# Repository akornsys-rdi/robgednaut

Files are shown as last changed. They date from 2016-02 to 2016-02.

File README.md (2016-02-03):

# robgednaut #


GNU/GPL (https://www.gnu.org/licenses/gpl.html "GNU General Public License")

### Robust and easy-to-use introduction-to-robotics platform ###

         ___     _              
        | _ \___| |__  ___ _ _  
        |   / _ \ '_ \/ -_) ' \ 
        |_|_\___/_.__/\___|_||_|

_Robgednaut_ (from **Rob**otic, Rug**ged**, and _-**naut**_ [like 
_astronaut_]), commonly _Roben_, it's a simple hardware platform for the 
introduction to robotics. Use an Arduino Nano to provide four multifunction 
connections. Also has ability to move up to two motors with the replaceable 
driver included. It can be used stand-alone or controlled from a computer, also 
it has numerous protections so you don't have to worry about if you break it!

Robgednaut is free software/hardware. See License Information below.

## Repository Contents ##

-   `/img/`: Graphic resources used --if not told otherwise-- as part of the 
documentation.  
-   `/3d/` 3D design source code.
    *   `/3d/bin/` Files resulting from the compilation of 3D designs (`STL` 
files).  
-   `/brd/` Hardware source code.  
    *    `/brd/bin/` Files resulting from the compilation of hardware (`PDF` 
and Gerber files).  
-   `/src/` Firmware source code.  
    *   `/src/bin/` Files resulting from the compilation of code (`HEX` files).

Robgednaut can be obtained on GitHub:
[Robgednaut](https://github.com/akornsys-rdi/robgednaut "Robgednaut").

## Installation and use ##

_Roben_ is very easy to use! You just need a Arduino Nano with the firmware we 
provide (compatible with firmata) or your own, your _Robgednaut_, and a power 
supply (3 to 32v max). Connect things to their I/O and enjoy making it work!  
It can be managed from Scratch by Firmata gateway, or from your own software.  
> **Warning**: Make sure you have the proper firmware BEFORE you connect your 
> Arduino Nano to _Robgednaut_. Not doing so may damage your Arduino.

#### Pinout ####

|Robgednaut|Arduino|Function|
|---|---|---|
| +V | - | 5v power out |
| GND | GND | Ground |
| A | D2, A7 | Analog input, digital I/O, `INT` |
| B | D3, A6 | Analog input, digital I/O, `INT`, `PWM` |
| C | D13, A4 | Analog input, digital I/O, `SDA`, `SCK` |
| D | D11, A5 | Analog input, digital I/O, `PWM`, `SCL`, `MOSI` |
| 1+ | D8 (en), D10 (`PWM`) | Half H-Bridge 1 output |
| 1- | D7 (en), D5 (`PWM`) | Half H-Bridge 1 output |
| 2+ | D8 (en), D9 (`PWM`) | Half H-Bridge 2 output |
| 2- | D7 (en), D6 (`PWM`) | Half H-Bridge 2 output |
| Internal | D4 | Piezo buzzer |
| Internal | D12 | Red LED |
| Internal | A0 | Yellow LED |
| Internal | A1 | Green LED |
| Internal | A2 | Push button |
| Internal | A3 | Push button |

## License Information ##

Firmware released under
[GNU/GPL](https://www.gnu.org/licenses/gpl.html "GNU General Public License").
See `/src/` folder.

The hardware design is released under
[GNU/GPL](https://www.gnu.org/licenses/gpl.html "GNU General Public License").
See `/brd/` folder.  
Source code hardware is considered any file created and stored by the CAD tool 
with design information. To KiCAD are mainly `SCH`, `NET`, `KICAD_PCB` files 
and associated.  
Binary hardware is considered any file created from source code. To KiCAD they 
are mainly `PDF`, `CSV` files and manufacturing files (e.g. gerber).  
Binary hardware execution is considered any process derived from binary 
hardware, such as manufacturing.

The 3D designs are released under
[GNU/GPL](https://www.gnu.org/licenses/gpl.html "GNU General Public License").
See `/3d/` folder.  
Source code 3D is considered any file created and stored by the CAD tool with 
design information. To OpenSCAD are mainly `SCAD` files.  
Binary 3D is considered any file created from source code. To OpenSCAD they are 
mainly rendering and manufacturing files (e.g. `STL`).  
Binary 3D execution is considered any process derived from binary 3D, such as 
manufacturing.

See the corresponding `COPYING` file.

## Version History ##

Robgednaut uses
[Semantic Versioning](http://semver.org/ "Semantic Versioning").

Robgednaut version 
[v2.0.0](https://github.com/akornsys-rdi/robgednaut/archive/v2.0.0.zip "v2.0.0")
is the latest stable version.

If you are interested, you can view the version history:
[`ChangeLog`](ChangeLog.md)

## Contribute ##

Feel free to submit bugs or patches, feature requests, etc. using
[GitHub issues](https://github.com/akornsys-rdi/robgednaut/issues "GitHub issues")
and
[Pull Requests](https://github.com/akornsys-rdi/robgednaut/pulls "Pull Requests")

You can read the information about the developers:
[`AUTHORS`](AUTHORS.md)

_Last modification: 2016-02-03_  
_This file was automatically generated by KodeUtils 1.0.2_

* * *

Copyright (C) 2015-2016 kwendenarmo. This file is part of Robgednaut

Robgednaut is free software; you can redistribute it and/or modify it under the 
terms of the GNU General Public License as published by the Free Software 
Foundation; either version 3 of the License, or (at your option) any later 
version.

Robgednaut is distributed in the hope that it will be useful, but WITHOUT ANY 
WARRANTY; without even the implied warranty of MERCHANTABILITY or FITNESS FOR A 
PARTICULAR PURPOSE.  See the GNU General Public License for more details

You should have received a copy of the GNU General Public License along with 
this program.  If not, see 
<[http://www.gnu.org/licenses/](http://www.gnu.org/licenses/ "http://www.gnu.org/licenses/")>.

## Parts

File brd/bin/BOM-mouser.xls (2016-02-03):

Robgednaut 2
Mouser REF | Fabr. N.º | Fabricante | Desc. | RoHS | Ciclo de vida | N.º Ref. del cliente | Ctd. pedido | Precio (EUR) | Ext.: (EUR)
855-M20-8771646 | M20-8771646 | Harwin | Alojamientos de cables y cabecera 16 SIL VERTICAL SMT HEADER TIN | Cumple RoHS |  |  | 1 | 0,733 € | 0,73 €
710-61303211821 | 61303211821 | Wurth Electronics | Alojamientos de cables y cabecera WR-PHD 2.54mm 32Pin Socket Header | Cumple RoHS |  |  | 1 | 1,48 € | 1,48 €
502-RAPC722X | RAPC722X | Switchcraft | Conectores de potencia de CC RT ANGL PWK JK PIN D | Cumple RoHS |  |  | 1 | 0,979 € | 0,98 €
667-ERJ-6ENF1802V | ERJ-6ENF1802V | Panasonic | Resistores de pel&iacute;cula gruesa - SMD 0805 18Kohms 1% Tol | Conforme con RoHS por exención |  |  | 1 | 0,091 € | 0,09 €
720-LYR976-PS-36 | LY R976-PS-36 | Osram Opto Semiconductor | LED estándar - SMD Yellow, 588nm 280mcd, 20mA | Cumple RoHS |  |  | 1 | 0,091 € | 0,09 €
720-LGR971-KN-1 | LG R971-KN-1 | Osram Opto Semiconductor | LED estándar - SMD Green, 570nm 26mcd, 20mA | Cumple RoHS |  |  | 1 | 0,091 € | 0,09 €
720-LSQ976-NR-1 | LS Q976-NR-1 | Osram Opto Semiconductor | LED estándar - SMD Super Red, 633nm 180mcd, 20mA | Cumple RoHS |  |  | 1 | 0,091 € | 0,09 €
511-LM2902DT | LM2902DT | STMicroelectronics | Amplificadores operacionales - Op Amps Quad Low Power | Cumple RoHS |  |  | 1 | 0,30 € | 0,30 €
506-FSM18JH | FSM18JH | TE Connectivity | Interruptores táctiles 6MM ACTHIGH TEMP TACT SWITCH | Cumple RoHS |  |  | 2 | 0,093 € | 0,19 €
665-AT1224TWT5V2R | AT-1224-TWT-5V-2-R | PUI Audio | Altavoces y transductores EM 5Vpk 2400Hz 87dBA Top Fire | Cumple RoHS |  |  | 1 | 0,503 € | 0,50 €
821-BZT52B5V1 | BZT52B5V1 | Taiwan Semiconductor | Diodos Zener 5.1 Volt 410mW 2% | Conforme con RoHS por exención |  |  | 4 | 0,162 € | 0,65 €
571-1-2199300-2 | 1-2199300-2 | TE Connectivity | Zócalos de CI y de componentes 32P DIP SKT 600 CL OTC | No aplicable |  |  | 1 | 0,701 € | 0,70 €
571-1-2199298-4 | 1-2199298-4 | TE Connectivity | Zócalos de CI y de componentes 16P DIP SKT 300 CL LADDER | Cumple RoHS |  |  | 1 | 0,115 € | 0,12 €
992-ARD-NANO30 | A000005 | Gravitech | Equipos y placas de desarrollo - AVR ARDUINO NANO V3 A000005 | Cumple RoHS |  |  | 1 | 30,79 € | 30,79 €
595-SN754410NE | SN754410NE | Texas Instruments | Controladores y unidades para motores / movimiento / ignición Quad Half-Hs | Cumple RoHS |  |  | 1 | 2,19 € | 2,19 €
611-JS202011SCQN | JS202011SCQN | C&K Components | Conmutadores deslizantes DPDT SMT .3A | Cumple RoHS |  |  | 1 | 0,40 € | 0,40 €
583-TCMBD914 | TCMBD914 | Rectron | Rectificadores 1N914 | Cumple RoHS |  |  | 1 | 0,043 € | 0,04 €
583-BC856A-T | BC856A-T | Rectron | Transistores bipolares - BJT Transistor PNP | Cumple RoHS |  |  | 1 | 0,065 € | 0,07 €
720-LOR976-PS-1 | LO R976-PS-1 | Osram Opto Semiconductor | LED estándar - SMD Orange, 606nm 280mcd, 20mA | Cumple RoHS |  |  | 9 | 0,091 € | 0,82 €
667-ERJ-6GEYJ221V | ERJ-6GEYJ221V | Panasonic | Resistores de pel&iacute;cula gruesa - SMD 0805 220ohms 5% Tol | Conforme con RoHS por exención |  |  | 17 | 0,016 € | 0,27 €
720-LBQ39GL2N2351 | LB Q39G-L2N2-35-1 | Osram Opto Semiconductor | LED estándar - SMD Blue, 470nm 45mcd, 5mA | Cumple RoHS |  |  | 1 | 0,146 € | 0,15 €
571-1776493-2 | 1776493-2 | TE Connectivity | Bloques terminales fijos SIDE WIRE ENTRY TB 5.08MM BL | Cumple RoHS |  |  | 1 | 0,317 € | 0,32 €
530-0ZCF0150FF2C | 0ZCF0150FF2C | Bel | Fusibles de restablecimiento (PPTC) Fuse | Cumple RoHS |  |  | 1 | 0,21 € | 0,21 €
621-B340-F | B340-13-F | Diodes Incorporated | Diodos y rectificadores Schottky 40V 3A | Conforme con RoHS por exención |  |  | 2 | 0,366 € | 0,73 €
771-BUK7Y98-80EX | BUK7Y98-80EX | NXP | MOSFET N-channel 80 V 98 mOhm MOSFET | Cumple RoHS |  |  | 1 | 0,471 € | 0,47 €
581-SD2114S040S8R0 | SD2114S040S8R0 | AVX | Diodos y rectificadores Schottky 40volts 8A SIZE 2114 | Cumple RoHS |  |  | 1 | 0,54 € | 0,54 €
652-SRR1210-220M | SRR1210-220M | Bourns | Inductores fijos 22uH 20% SMD 1210 | Cumple RoHS |  |  | 1 | 1,00 € | 1,00 €
652-SDR1307-680KL | SDR1307-680KL | Bourns | Inductores fijos 68uH 10% SMD 1307 | Cumple RoHS |  |  | 1 | 0,786 € | 0,79 €
667-ERJ-6ENF1543V | ERJ-6ENF1543V | Panasonic | Resistores de pel&iacute;cula gruesa - SMD 0805 154Kohms 1% Tol | Conforme con RoHS por exención |  |  | 1 | 0,091 € | 0,09 €
667-ERJ-6ENF2942V | ERJ-6ENF2942V | Panasonic | Resistores de pel&iacute;cula gruesa - SMD 0805 29.4Kohms 1% Tol | Conforme con RoHS por exención |  |  | 1 | 0,091 € | 0,09 €
667-ERJ-6ENF1002V | ERJ-6ENF1002V | Panasonic | Resistores de pel&iacute;cula gruesa - SMD 0805 10Kohms 1% Tol | Conforme con RoHS por exención |  |  | 7 | 0,10 € | 0,70 €
667-ERJ-6ENF1961V | ERJ-6ENF1961V | Panasonic | Resistores de pel&iacute;cula gruesa - SMD 0805 1.96Kohms 1% Tol | Conforme con RoHS por exención |  |  | 1 | 0,091 € | 0,09 €
667-ERJ-6ENF1000V | ERJ-6ENF1000V | Panasonic | Resistores de pel&iacute;cula gruesa - SMD 0805 100ohms 1% Tol | Conforme con RoHS por exención |  |  | 1 | 0,10 € | 0,10 €
667-ERJ-6ENF20R0V | ERJ-6ENF20R0V | Panasonic | Resistores de pel&iacute;cula gruesa - SMD 0805 20.0ohms 1% Tol | Conforme con RoHS por exención |  |  | 1 | 0,091 € | 0,09 €
754-KRL1632EMR018FT5 | KRL1632E-M-R018-F-T5 | Susumu | Resistores de detecci&oacute;n de corriente - SMD 3/4w 18m ohm 1% | Cumple RoHS |  |  | 1 | 0,494 € | 0,49 €
647-UWT1A471MNL1GS | UWT1A471MNL1GS | Nichicon | Capacitadores electrolíticos de aluminio - SMD 10volts 470uF 105c 8x10 | Cumple RoHS |  |  | 2 | 0,485 € | 0,97 €
140-VE100M1HTR0505 | VE-100M1HTR-0505 | Lelon | Capacitadores electrolíticos de aluminio - SMD 50 Volts 10uF 20% 5x5.3 | Cumple RoHS |  |  | 1 | 0,205 € | 0,21 €
963-UMK316AB7475KL-T | UMK316AB7475KL-T | Taiyo Yuden | Condensadores de cerámica multicapa (MLCC- SMD/SMT) 4.7uF 50Volts X7R +/-10% 1206 STD | Cumple RoHS |  |  | 1 | 0,256 € | 0,26 €
77-VJ0805Y394KXJTBC | VJ0805Y394KXJTW1BC | Vishay | Condensadores de cerámica multicapa (MLCC- SMD/SMT) 0805 0.39uF 16volts X7R 10% | Cumple RoHS |  |  | 1 | 0,091 € | 0,09 €
80-C0805C104K5R | C0805C104K5RACTU | Kemet | Condensadores de cerámica multicapa (MLCC- SMD/SMT) 50volts 0.1uF X7R 10% | Cumple RoHS |  |  | 3 | 0,091 € | 0,27 €
81-GRM2165C1H242JA01 | GRM2165C1H242JA01D | Murata | Condensadores de cerámica multicapa (MLCC- SMD/SMT) 0805 2400pF 50volts C0G 5% | Cumple RoHS |  |  | 1 | 0,199 € | 0,20 €
81-GRM2165C1H162JA1D | GRM2165C1H162JA01D | Murata | Condensadores de cerámica multicapa (MLCC- SMD/SMT) 0805 1600pF 50volt C0G +/-5% | Cumple RoHS |  |  | 1 | 0,181 € | 0,18 €
926-LM3488MM/NOPB | LM3488MM/NOPB | Texas Instruments | Controladores de conmutación HI EFF LOW-SIDE N CH CONTROLLER | Cumple RoHS |  |  | 1 | 1,92 € | 1,92 €

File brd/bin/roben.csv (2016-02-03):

Source: | /home/kwendenarmo/git-repos/local/akornsys-rdi/robgednaut/brd/roben.sch
Date: | mié 03 feb 2016 19:03:34 CET
Tool: | Eeschema 4.0.1-3.201512221402+6198~38~ubuntu14.04.1-stable
Generator: | /usr/share/doc/kicad/scripts/bom-in-python/bom_csv_grouped_by_value_with_fp.py
Component Count: | 90
Ref | Qnty | Value | Cmp name | Footprint | Description | Vendor
C1, | 1 | 10uF | CP | Capacitors_SMD:c_elec_5x5.3 | Polarised capacitor | VE-100M1HTR-0505
C3, | 1 | 1.6nF | C | Capacitors_SMD:C_0805_HandSoldering | Unpolarized capacitor | GRM2165C1H162JA01D
C4, | 1 | 390nF | C | Capacitors_SMD:C_0805_HandSoldering | Unpolarized capacitor | VJ0805Y394KXJTW1BC
C5, | 1 | 2.4nF | C | Capacitors_SMD:C_0805_HandSoldering | Unpolarized capacitor | GRM2165C1H242JA01D
C6, | 1 | 4.7uF | C | Capacitors_SMD:C_1206_HandSoldering | Unpolarized capacitor | UMK316AB7475KL-T
C7, C8, | 2 | 470uF | CP | Capacitors_SMD:c_elec_8x10 | Polarised capacitor | UWT1A471MNL1GS
C9, C2, C10, | 3 | 100nF | C | Capacitors_SMD:C_0805_HandSoldering | Unpolarized capacitor | C0805C104K5RACTU
D1, | 1 | RED | LED | LEDs:LED-0805 |  | LS Q976-NR-1
D3, | 1 | YELLOW | LED | LEDs:LED-0805 |  | LY R976-PS-36
D4, | 1 | GREEN | LED | LEDs:LED-0805 |  | LG R971-KN-1
D5, | 1 | SD2114S040S8R0 | D | Diodes_SMD:Diode-SMB_Handsoldering | Diode | SD2114S040S8R0
D6, | 1 | BLUE | LED | LEDs:LED-0805 |  | LB Q39G-L2N2-35-1
D11, | 1 | TCMBD914 | Diode-sot23 | Housings_SOT-23_SOT-143_TSOT-6:SOT-23_Handsoldering | Diode | TCMBD914
D13, D2, | 2 | B340 | D_Schottky | Diodes_SMD:Diode-SMC_Handsoldering | Diode schottky | B340-F
D14, D18, D15, D19, | 4 | 5V1 | ZENER | Diodes_SMD:SOD-123 | Diode zener | BZT52B5V1
D16, D12, D20, D17, D21, D7, D8, D9, D10, | 9 | ORANGE | LED | LEDs:LED-0805 |  | LO R976-PS-1
F1, | 1 | 1.5A PPTC | F_Small | Fuse_Holders_and_Fuses:Fuse_SMD2920 | Fuse | 0ZCF0150FF2C
J1, | 1 | POWER IN | CONN_01X03 | asrdi-conn:combo-barrel5.5x2.1-2p5.08 | Connector 01x03 | 1776493-2 / RAPC722X
J2, | 1 | BT HC-05 | CONN_01X06 | asrdi-socket:HC-05 | Connector 01x06 | 61303211821
J3, | 1 | 1+ | CONN_01X01 | Wire_Pads:SolderWirePad_single_2-5mmDrill | Connector 01x01
J4, | 1 | 1- | CONN_01X01 | Wire_Pads:SolderWirePad_single_2-5mmDrill | Connector 01x01
J5, | 1 | 2+ | CONN_01X01 | Wire_Pads:SolderWirePad_single_2-5mmDrill | Connector 01x01
J6, | 1 | 2- | CONN_01X01 | Wire_Pads:SolderWirePad_single_2-5mmDrill | Connector 01x01
J7, J9, | 2 | +V | CONN_01X01 | Wire_Pads:SolderWirePad_single_2-5mmDrill | Connector 01x01
J10, J8, | 2 | GND | CONN_01X01 | Wire_Pads:SolderWirePad_single_2-5mmDrill | Connector 01x01
J11, | 1 | A | CONN_01X01 | Wire_Pads:SolderWirePad_single_2-5mmDrill | Connector 01x01
J12, | 1 | C | CONN_01X01 | Wire_Pads:SolderWirePad_single_2-5mmDrill | Connector 01x01
J13, | 1 | B | CONN_01X01 | Wire_Pads:SolderWirePad_single_2-5mmDrill | Connector 01x01
J14, | 1 | D | CONN_01X01 | Wire_Pads:SolderWirePad_single_2-5mmDrill | Connector 01x01
JP1, | 1 | VSEL | JUMPER3 | asrdi-conn:M20-87703xx |  | M20-8771646
L1, | 1 | 22uH | INDUCTOR | asrdi-discrete:coil-12x12h10 |  | SRR1210-220M
L2, | 1 | 68uH | INDUCTOR | asrdi-discrete:coil-13x13H7 |  | SDR1307-680KL
LS1, | 1 | AT-1224-TWT-5V-2-R | Crystal | asrdi-buzzer:AT-1224-TWT-5V-2-R | Two pin crystal | AT-1224-TWT-5V-2-R
Q1, | 1 | BUK7Y98 | IRF8721PBF-1 | Power_Packages_SMD:SOT-669_LFPAK_ThermalVias-1 | 30V Vds, 14A Id, HEXFET MOSFET, SO-8 | BUK7Y98-80EX
Q2, | 1 | BC856 | Q_PNP_CBE | Housings_SOT-23_SOT-143_TSOT-6:SOT-23_Handsoldering | Transistor PNP (general) | BC856A-T
R2, | 1 | 18k | R | Resistors_SMD:R_0805_HandSoldering | Resistor | ERJ-6ENF1802V
R6, | 1 | 20R | R | Resistors_SMD:R_0805_HandSoldering | Resistor | ERJ-6ENF20R0V
R8, | 1 | 154k | R | Resistors_SMD:R_0805_HandSoldering | Resistor | ERJ-6ENF1543V
R9, | 1 | 1k96 | R | Resistors_SMD:R_0805_HandSoldering | Resistor | ERJ-6ENF1961V
R14, | 1 | 100R | R | Resistors_SMD:R_0805_HandSoldering | Resistor | ERJ-6ENF1000V
R15, | 1 | 18m | R | asrdi-discrete:0612 | Resistor | KRL1632E-M-R018-F-T5
R16, | 1 | 29k4 | R | Resistors_SMD:R_0805_HandSoldering | Resistor | ERJ-6ENF2942V
R17, R1, R12, R7, R5, R13, R3, | 7 | 10k | R | Resistors_SMD:R_0805_HandSoldering | Resistor | ERJ-6ENF1002V
R24, R22, R26, R10, R11, R4, R23, R28, R30, R25, R27, R29, R31, R18, R19, R20, R21, | 17 | 220R | R | Resistors_SMD:R_0805_HandSoldering | Resistor | ERJ-6GEYJ221V
SW1, | 1 | POWER ON | Switch_SPDT_x2 | asrdi-switch:JS202011SCQN | Double Single Pole Double Throw (SPDT) switch | JS202011SCQN
SW2, SW3, | 2 | SW_PUSH | SW_PUSH | asrdi-switch:FSMxxJxH | Button | FSM18JH
U1, | 1 | Ardunano | Ardunano | asrdi-socket:Ardunano |  | A000005 / 1-2199300-2
U2, | 1 | LM3488 | LM3488 | Housings_SSOP:TSSOP-8_3x3mm_Pitch0.65mm |  | LM3488MM/NOPB
U3, | 1 | SN754410N | SN754410N | Housings_DIP:DIP-16__300_ELL |  | SN754410NE / 1-2199298-4
U4, | 1 | LM2902N | LM2902N | Housings_SOIC:SOIC-14_3.9x8.7mm_Pitch1.27mm | Quad Op amp. | LM2902DT

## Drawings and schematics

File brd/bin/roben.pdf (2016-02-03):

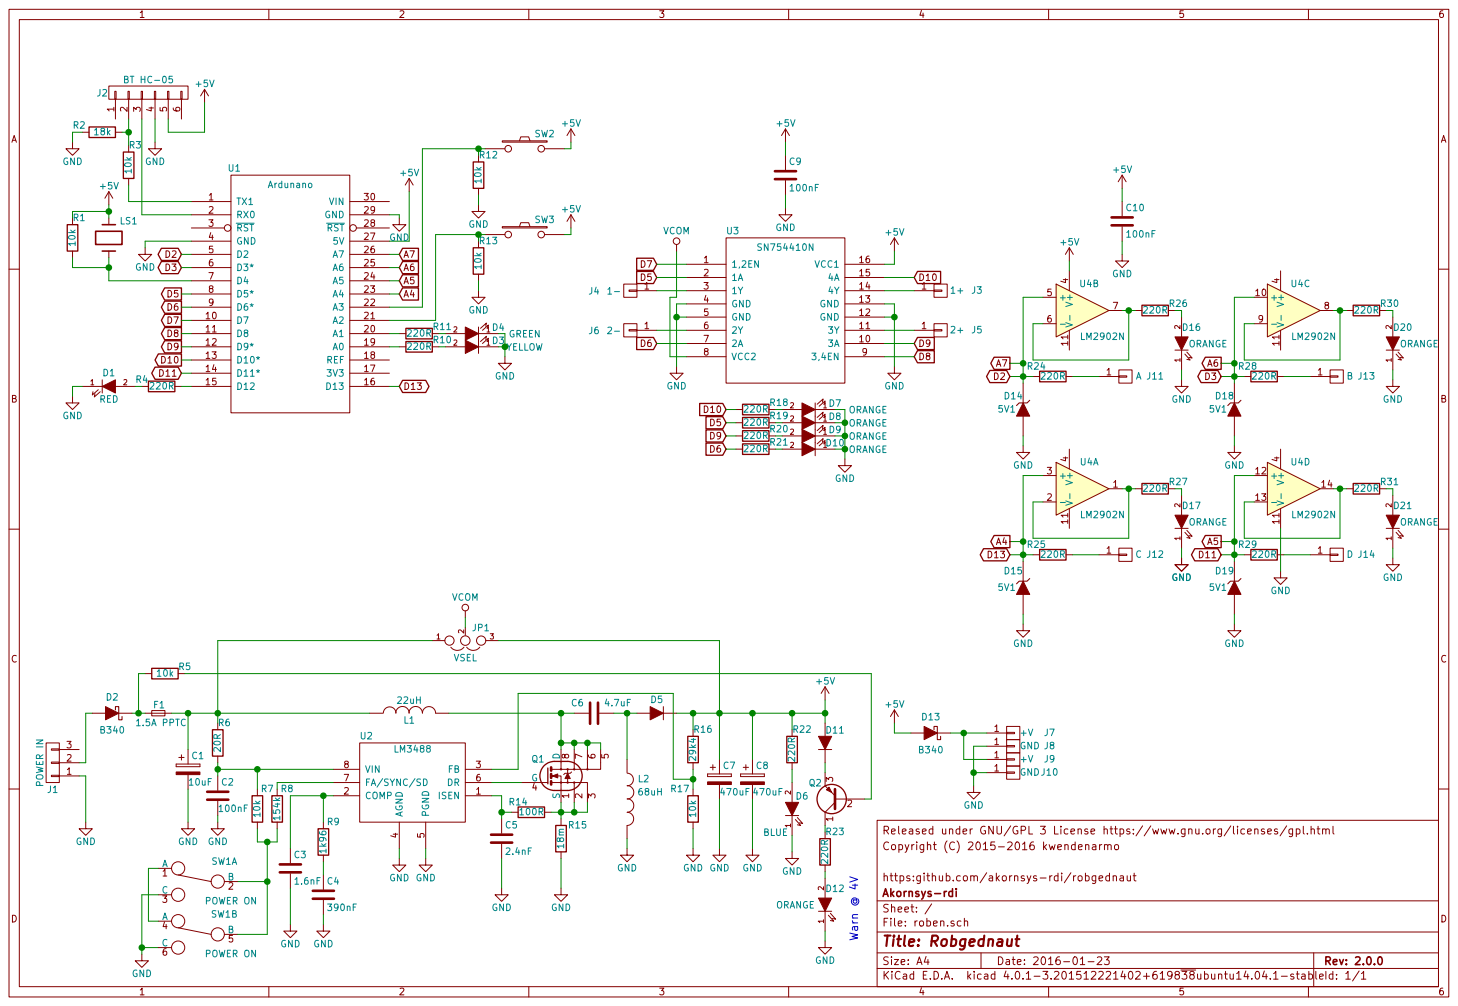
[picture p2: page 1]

5 DR 6 FA/SYNC/SD 7 VIN 8 U2

Released under GNU/GPL 3 License https://www.gnu.org/licenses/gpl.html
Copyright (C) 2015-2016 kwendenarmo

https:github.com/akornsys-rdi/robgednaut
Id: 1/1 Title: Robgednaut File: roben.sch Sheet: / Akornsys-rdi

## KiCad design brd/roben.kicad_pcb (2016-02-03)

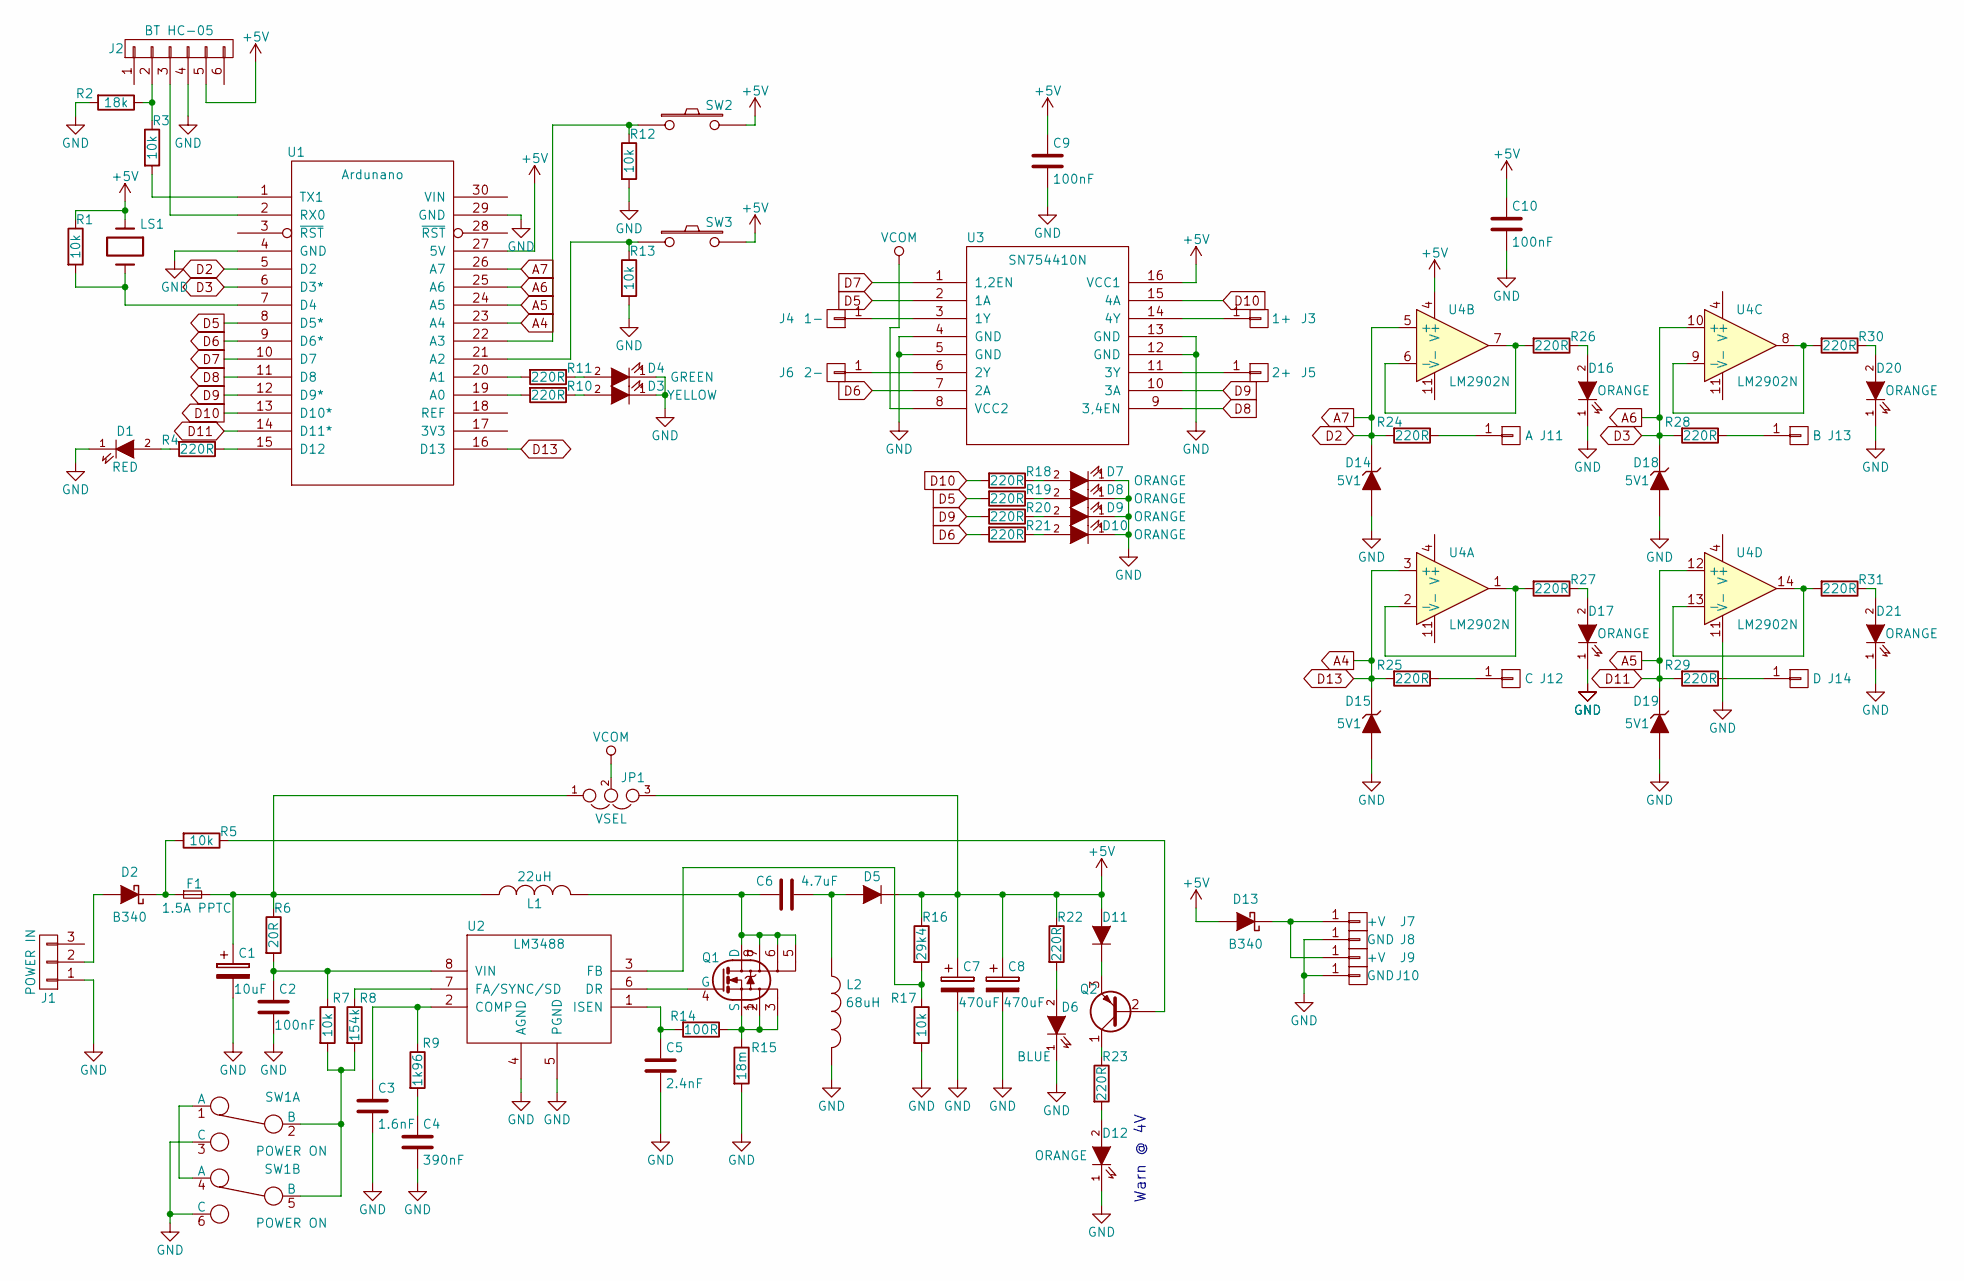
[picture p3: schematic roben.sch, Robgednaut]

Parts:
C1: 10uF; c_elec_5x5.3
C2, C9, C10: 100nF; C_0805_HandSoldering
C3: 1.6nF; C_0805_HandSoldering
C4: 390nF; C_0805_HandSoldering
C5: 2.4nF; C_0805_HandSoldering
C6: 4.7uF; C_1206_HandSoldering
C7, C8: 470uF; c_elec_8x10
D1: RED; LED-0805
D2, D13: B340; Diode-SMC_Handsoldering
D3: YELLOW; LED-0805
D4: GREEN; LED-0805
D5: SD2114S040S8R0; Diode-SMB_Handsoldering
D6: BLUE; LED-0805
D7, D8, D9, D10, D12, D16, D17, D20, D21: ORANGE; LED-0805
D11: TCMBD914; SOT-23_Handsoldering
D14, D15, D18, D19: 5V1; SOD-123
F1: 1.5A PPTC; Fuse_SMD2920
J1: POWER IN; combo-barrel5.5x2.1-2p5.08
J2: BT HC-05; HC-05
J3: 1+; SolderWirePad_single_2-5mmDrill
J4: 1-; SolderWirePad_single_2-5mmDrill
J5: 2+; SolderWirePad_single_2-5mmDrill
J6: 2-; SolderWirePad_single_2-5mmDrill
J7, J9: +V; SolderWirePad_single_2-5mmDrill
J8, J10: GND; SolderWirePad_single_2-5mmDrill
J11: A; SolderWirePad_single_2-5mmDrill
J12: C; SolderWirePad_single_2-5mmDrill
J13: B; SolderWirePad_single_2-5mmDrill
J14: D; SolderWirePad_single_2-5mmDrill
JP1: VSEL; M20-87703xx
L1: 22uH; coil-12x12h10
L2: 68uH; coil-13x13H7
LS1: AT-1224-TWT-5V-2-R
Q1: BUK7Y98; SOT-669_LFPAK_ThermalVias-1
Q2: BC856; SOT-23_Handsoldering
R1, R3, R5, R7, R12, R13, R17: 10k; R_0805_HandSoldering
R2: 18k; R_0805_HandSoldering
R4, R10, R11, R18, R19, R20, R21, R22, R23, R24, R25, R26, R27, R28, R29, R30, R31: 220R; R_0805_HandSoldering
R6: 20R; R_0805_HandSoldering
R8: 154k; R_0805_HandSoldering
R9: 1k96; R_0805_HandSoldering
R14: 100R; R_0805_HandSoldering
R15: 18m; 0612
R16: 29k4; R_0805_HandSoldering
SW1: POWER ON; JS202011SCQN
SW2, SW3: SW_PUSH; FSMxxJxH
U1: Ardunano
U2: LM3488; TSSOP-8_3x3mm_Pitch0.65mm
U3: SN754410N; DIP-16__300_ELL
U4: LM2902N; SOIC-14_3.9x8.7mm_Pitch1.27mm

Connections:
+5V: C7.1, C8.1, C9.1, C10.1, D5.1 (K), D11.1 (A), D13.2 (A), J2.5, JP1.3, LS1.1, R1.1, R16.1, R22.1, SW2.2, SW3.2, U1.27 (5V), U3.16 (VCC1), U4.4 (V+)
A4: D15.1 (K), R25.2, U1.16 (D13), U1.23 (A4), U4.3 (+)
A5: D19.1 (K), R29.2, U1.14 (D11*), U1.24 (A5), U4.12 (+)
A6: D18.1 (K), R28.2, U1.6 (D3*), U1.25 (A6), U4.10 (+)
A7: D14.1 (K), R24.2, U1.5 (D2), U1.26 (A7), U4.5 (+)
D5: R19.2, U1.8 (D5*), U3.2 (1A)
D6: R21.2, U1.9 (D6*), U3.7 (2A)
D7: U1.10 (D7), U3.1 (1,2EN)
D8: U1.11 (D8), U3.9 (3,4EN)
D9: R20.2, U1.12 (D9*), U3.10 (3A)
D10: R18.2, U1.13 (D10*), U3.15 (4A)
GND: C1.2, C2.2, C3.2, C4.2, C5.2, C7.2, C8.2, C9.2, C10.2, D1.1 (K), D3.1 (K), D4.1 (K), D6.1 (K), D7.1 (K), D8.1 (K), D9.1 (K), D10.1 (K), D12.1 (K), D14.2 (A), D15.2 (A), D16.1 (K), D17.1 (K), D18.2 (A), D19.2 (A), D20.1 (K), D21.1 (K), J1.1, J2.4, J8.1, J10.1, L2.2, R2.2, R12.2, R13.2, R15.2, R17.2, SW1.3 (C), SW1.6 (C), U1.4 (GND), U1.29 (GND), U2.4 (AGND), U2.5 (PGND), U3.4 (GND), U3.5 (GND), U3.12 (GND), U3.13 (GND), U4.11 (V-)
unnamed: C1.1, F1.2, JP1.1, L1.1, R6.1
unnamed: C2.1, R6.2, R7.1, U2.8 (VIN)
unnamed: C3.1, R9.1, U2.2 (COMP)
unnamed: C4.1, R9.2
unnamed: C5.1, R14.2, U2.1 (ISEN)
unnamed: C6.1, D5.2 (A), L2.1
unnamed: C6.2, L1.2, Q1.5, Q1.6, Q1.7, Q1.8 (D)
unnamed: D1.2 (A), R4.2
unnamed: D2.1 (K), F1.1, R5.2
unnamed: D2.2 (A), J1.2
unnamed: D3.2 (A), R10.1
unnamed: D4.2 (A), R11.1
unnamed: D6.2 (A), R22.2
unnamed: D7.2 (A), R18.1
unnamed: D8.2 (A), R19.1
unnamed: D9.2 (A), R20.1
unnamed: D10.2 (A), R21.1
unnamed: D11.3 (K), Q2.3 (E)
unnamed: D12.2 (A), R23.2
unnamed: D13.1 (K), J7.1, J9.1
unnamed: D16.2 (A), R26.1
unnamed: D17.2 (A), R27.1
unnamed: D20.2 (A), R30.1
unnamed: D21.2 (A), R31.1
unnamed: J2.2, R2.1, R3.1
unnamed: J2.3, U1.2 (RX0)
unnamed: J3.1, U3.14 (4Y)
unnamed: J4.1, U3.3 (1Y)
unnamed: J5.1, U3.11 (3Y)
unnamed: J6.1, U3.6 (2Y)
unnamed: J11.1, R24.1
unnamed 43: J12.1, R25.1; also elsewhere on the board
unnamed 44: J13.1, R28.1; also elsewhere on the board
unnamed 45: J14.1, R29.1; also elsewhere on the board
unnamed: LS1.2, R1.2, U1.7 (D4)
unnamed: Q1.1 (S), Q1.2, Q1.3, R14.1, R15.1
unnamed: Q1.4 (G), U2.6 (DR)
unnamed: Q2.1 (C), R23.1
unnamed: Q2.2 (B), R5.1
unnamed: R3.2, U1.1 (TX1)
unnamed: R4.1, U1.15 (D12)
unnamed: R7.2, R8.2, SW1.2 (B), SW1.5 (B)
unnamed: R8.1, U2.7 (FA/SYNC/SD)
unnamed: R10.2, U1.19 (A0)
unnamed: R11.2, U1.20 (A1)
unnamed: R12.1, SW2.1, U1.22 (A3)
unnamed: R13.1, SW3.1, U1.21 (A2)
unnamed: R16.2, R17.1, U2.3 (FB)
unnamed: R26.2, U4.6 (-), U4.7
unnamed: R27.2, U4.1, U4.2 (-)
unnamed: R30.2, U4.8, U4.9 (-)
unnamed: R31.2, U4.13 (-), U4.14
unnamed: SW1.1 (A), SW1.4 (A)
VCOM: JP1.2, U3.8 (VCC2)

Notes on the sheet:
Warn @ 4V

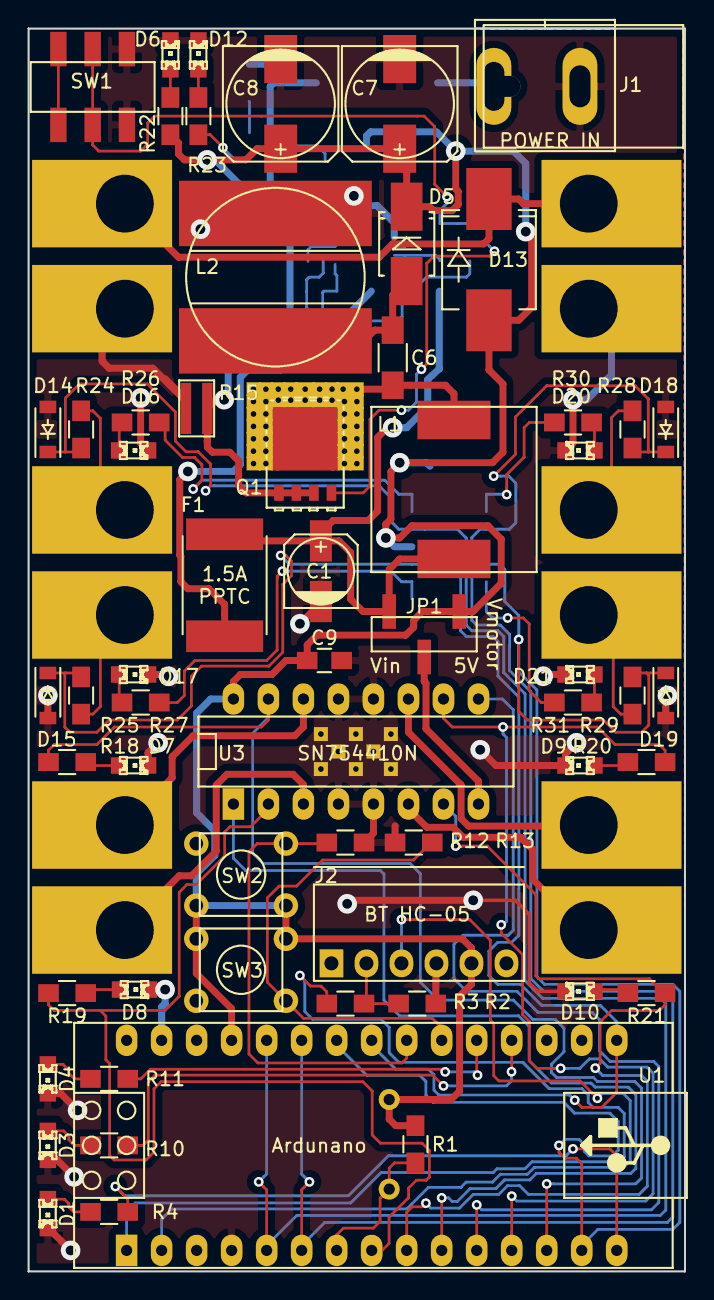
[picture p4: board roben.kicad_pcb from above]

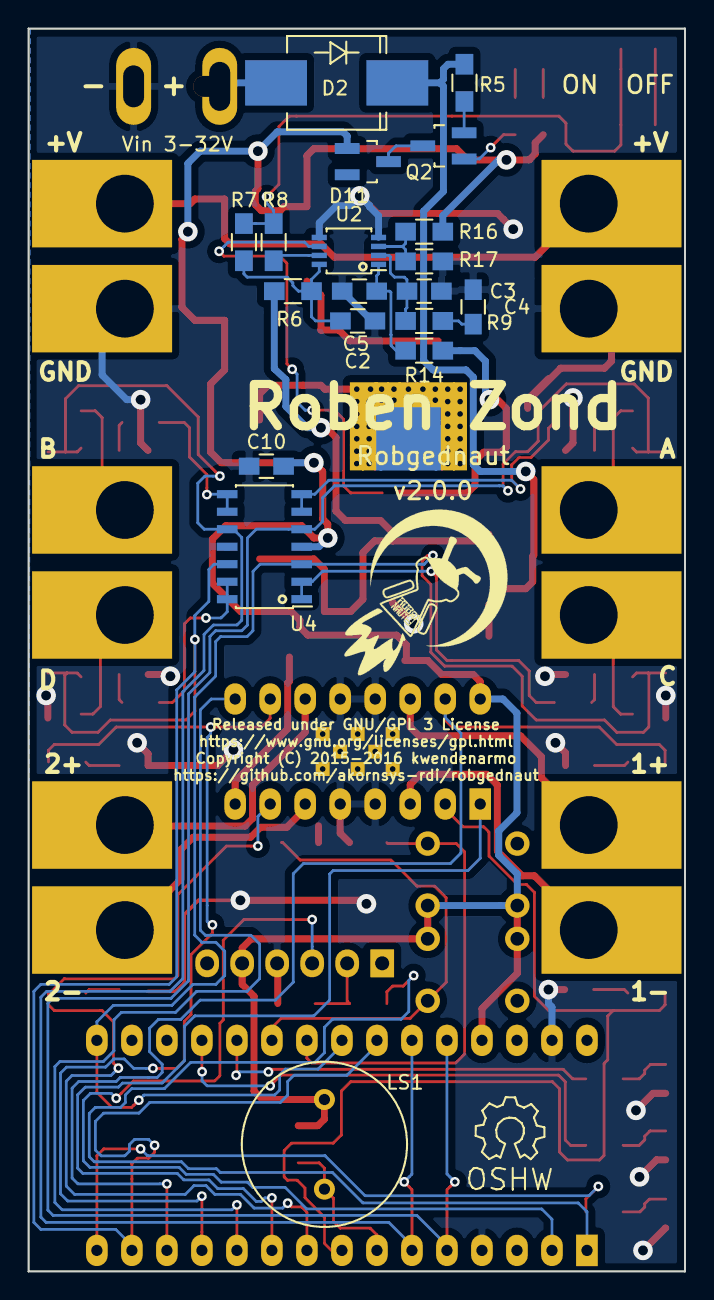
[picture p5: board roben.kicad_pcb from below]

Board: 2 copper layers, 47.6 x 90.2 mm, 91 parts (20 on the bottom side), 66 nets.

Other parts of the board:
B: B; SolderWirePad_single_2-5mmDrill
C: C; SolderWirePad_single_2-5mmDrill
D: D; SolderWirePad_single_2-5mmDrill
G1: LOGO; roben

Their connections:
unnamed 43: C.1; also elsewhere on the board
unnamed 44: B.1; also elsewhere on the board
unnamed 45: D.1; also elsewhere on the board

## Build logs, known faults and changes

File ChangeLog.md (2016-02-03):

# robgednaut #

## v2.0.0 (2016-02-03 21:07:56 +0100) ##

-   Merge branch 'dev' (ea87400) [kwendenarmo]  
-   chg: modificados archivos README (2095d0f) [kwendenarmo]  
-   chg: añadido logo robgednaut (05b1413) [kwendenarmo]  
-   chg: añadidos BOM (879a797) [kwendenarmo]  
-   chg: generados archivos gerbers (65fa47a) [kwendenarmo]  
-   chg: corregidos errores (54a3575) [kwendenarmo]  
-   chg: diseñado pcb (0aa2eb8) [kwendenarmo]  
-   chg: generado pdf de esquematico (6a36658) [kwendenarmo]  
-   chg: reordenadas salidas LED (575e865) [kwendenarmo]  
-   chg: BREAKING reasignadas uniones I/O (9104eee) [kwendenarmo]  
-   chg: reordenados LED de motores en consonancia (ce2735c) [kwendenarmo]  
-   chg: BREAKING intercambiadas salidas de motores (cc0f961) [kwendenarmo]  
-   chg: BREAKING desplazadas conexiones analogicas (ebe521a) [kwendenarmo]  
-   chg: mejoradas asociaciones de zócalos, resuelto #3 (3adda39) 
[kwendenarmo]  
-   chg: reanotados componentes (63fb064) [kwendenarmo]  
-   chg: corregida conexion bluetooth (e7f7556) [kwendenarmo]  
-   chg: finalizado esquematico (fccc090) [kwendenarmo]  
-   chg: creada netlist y asociaciones (879a406) [kwendenarmo]  
-   chg: actualizada informacion de esquematico (05a892c) [kwendenarmo]  
-   chg: anotados componentes en esquematico (92b83ad) [kwendenarmo]  
-   chg: añadida comunicacion bluetooth (00d5ea8) [kwendenarmo]  
-   chg: añadidos indicadores de salida en motores (3735713) [kwendenarmo]  
-   chg: añadido seleccion de tension para motores (6d45aea) [kwendenarmo]  
-   chg: optimizado esquemático y circuito (c8d9137) [kwendenarmo]  
-   new: añadido indicador de bateria baja, segun #7 (6b159d9) [kwendenarmo]  
-   new: añadido interruptor de encendido, segun #6 (56736e5) [kwendenarmo]  
-   new: añadidos periféricos en pines libres, segun #4 (238fac0) 
[kwendenarmo]  
-   new: reemplazado step-down por sepic, segun #2 (c6fa1af) [kwendenarmo]  
-   new: modificada inversión de polaridad según #1 (eda3754) [kwendenarmo]  
-   chg::doc: actualizados archivos README (ae55fe1) [kwendenarmo]  
-   Merge branch 'dev' (50cd418) [kwendenarmo]  
-   new: importado ``robgednaut-firmware`` (19c5e0d) [kwendenarmo]  
-   new: movido src a ``robgednaut-firmware`` repo (0113481) [kwendenarmo]  
-   chg: dev: subido codigo demo !wip (1088910) [kwendenarmo]  
-   chg: dev: añadidas referencias datasheet y BOM (1f88c82) [kwendenarmo]  
-   new: dev: subida PCB (7137780) [kwendenarmo]  
-   new: doc: Subidos conjunto de archivos README (60098a3) [kwendenarmo]  
-   Initial commit (a08f8ef) [kwendenarmo]  

## v1.0.0 (2016-01-17 18:32:07 +0100) ##

-   Merge branch 'dev' (50cd418) [kwendenarmo]  
-   new: importado ``robgednaut-firmware`` (19c5e0d) [kwendenarmo]  
-   new: movido src a ``robgednaut-firmware`` repo (0113481) [kwendenarmo]  
-   chg: dev: subido codigo demo !wip (1088910) [kwendenarmo]  
-   chg: dev: añadidas referencias datasheet y BOM (1f88c82) [kwendenarmo]  
-   new: dev: subida PCB (7137780) [kwendenarmo]  
-   new: doc: Subidos conjunto de archivos README (60098a3) [kwendenarmo]  
-   Initial commit (a08f8ef) [kwendenarmo]  

_Last modification: 2016-02-03_  
_This file was automatically generated by KodeUtils 1.0.2_

* * *

Copyright (C) 2015-2016 kwendenarmo. This file is part of Robgednaut

Robgednaut is free software; you can redistribute it and/or modify it under the 
terms of the GNU General Public License as published by the Free Software 
Foundation; either version 3 of the License, or (at your option) any later 
version.

Robgednaut is distributed in the hope that it will be useful, but WITHOUT ANY 
WARRANTY; without even the implied warranty of MERCHANTABILITY or FITNESS FOR A 
PARTICULAR PURPOSE.  See the GNU General Public License for more details

You should have received a copy of the GNU General Public License along with 
this program.  If not, see 
<[http://www.gnu.org/licenses/](http://www.gnu.org/licenses/ "http://www.gnu.org/licenses/")>.

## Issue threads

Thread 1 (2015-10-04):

Protección inversión de entrada

kwendenarmo, 2015-10-04:
En lugar de provocar un corto a través de D1 y F1 cuando se invierte la polaridad en la entrada, poner D1 en serie con F1, impidiendo que la corriente pueda fluir en caso de inversión de polaridad. Igualmente el valor de F1 no se vuelte tan crítico ni ha de asumir el flujo de corriente hasta pasar a estado de alta resistencia, tiempo durante el cual D1 puede dañarse.

Closed 2016-01-18.

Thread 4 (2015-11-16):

Añadir LED

kwendenarmo, 2015-11-16:
Añadir un LED por salida, y otros fijos en la placa usando pines directos del Arduino Nano.

kwendenarmo, 2016-01-18:
Los pines de salida deben ir a través de un seguidor de tensión, para cuando esos pines actúan como entrada.

Además, puede ser buena idea que los pines libres de Arduino vayan a LED, buzzers, pulsadores o algún otro periférico.

Closed 2016-01-18.

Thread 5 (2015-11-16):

Compatibilidad alimentación con barrel jack?

kwendenarmo, 2015-11-16:
Mirar la posibilidad de preparar la PCB para montar bloque terminal o barrel jack indistintamente como conector de alimentación.

kwendenarmo, 2016-01-21:
En un principio, podría ser compatible con un barrel jack de 5.5/2.1mm.

Closed 2016-02-03.

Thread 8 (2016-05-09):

No funciona el avisador de batería baja

kwendenarmo, 2016-05-09:
Revisar por qué no funciona correctamente el indicador de batería baja, que se queda permanentemente encendido.

kwendenarmo, 2016-05-10:
Según el esquemático, el transistor BC856 es CBE, mientras que el componente es BEC. Correctamente montado funciona perfectamente.

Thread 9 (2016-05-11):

Encapsulado resistencia sensing

kwendenarmo, 2016-05-11:
La resistencia de detección de corriente está en el encapsulado reversed, corregirlo o cambiarlo en el BOM

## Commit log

2015-09-10 new: doc: Subidos conjunto de archivos README
2015-09-10 new: dev: subida PCB
    [roben.kicad_pcb, roben.sch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]
2015-09-10 chg: dev: añadidas referencias datasheet y BOM
    [BOM-mouser.xls, roben.csv, roben.sch]
2016-01-17 new: modificada inversión de polaridad según #1
    [roben.sch]
2016-01-18 new: reemplazado step-down por sepic, segun #2
    [roben.sch]
2016-01-18 new: añadidos periféricos en pines libres, segun #4
    [roben.sch]
2016-01-18 new: añadido interruptor de encendido, segun #6
    [roben.sch]
2016-01-18 new: añadido indicador de bateria baja, segun #7
    [roben.sch]
2016-01-23 chg: optimizado esquemático y circuito
    [roben.sch]
2016-01-23 chg: añadido seleccion de tension para motores
    [roben.sch]
2016-01-23 chg: añadidos indicadores de salida en motores
    [roben.sch]
2016-01-23 chg: añadida comunicacion bluetooth
    [roben.sch]
2016-01-23 chg: anotados componentes en esquematico
    [roben.sch]
2016-01-23 chg: actualizada informacion de esquematico
    [roben.sch]
2016-01-23 chg: creada netlist y asociaciones
    [roben.sch]
2016-01-23 chg: finalizado esquematico
    [roben.sch]
2016-01-31 chg: corregida conexion bluetooth
    [roben.sch]
2016-01-31 chg: reanotados componentes
    [roben.sch]
2016-01-31 chg: mejoradas asociaciones de zócalos, resuelto #3
2016-01-31 chg: BREAKING desplazadas conexiones analogicas
    [roben.sch]
2016-01-31 chg: BREAKING intercambiadas salidas de motores
    [roben.sch]
2016-01-31 chg: reordenados LED de motores en consonancia
    [roben.sch]
2016-01-31 chg: BREAKING reasignadas uniones I/O
    [roben.sch]
2016-01-31 chg: reordenadas salidas LED
    [roben.sch]
2016-02-02 chg: generado pdf de esquematico
2016-02-02 chg: diseñado pcb
    [roben.kicad_pcb]
2016-02-02 chg: corregidos errores
    [roben.kicad_pcb]
2016-02-02 chg: generados archivos gerbers
    [robgednaut-back.gbl, robgednaut-front.gtl, robgednaut-mask-back.gbs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]
2016-02-03 chg: añadidos BOM
    [BOM-mouser.xls, roben.csv]
